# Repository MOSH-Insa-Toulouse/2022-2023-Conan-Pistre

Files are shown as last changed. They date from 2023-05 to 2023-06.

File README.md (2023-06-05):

# 2022-2023-Conan-Pistre

fake-it-till-u-make-it (1)




Ce projet s'inscrit dans l'UF "*Du capteur au banc de Test*". Il consiste en l'élaboration d'un capteur de déformation/Jauge de contrainte à base de graphite.
**Design**, **Conception**, **Test** et **Codage** de notre Capteur et de son circuit sont détaillés ci-dessous.

## Descriptif du Projet

Notre projet se sépare en deux axes précis:
 - Le développement d'une partie *Professionnelle* permettant depuis une application et un affichage OLED d'obtenir les valeurs de résistance de notre capteur
 - Le développement d'une partie *Fun* permettant une application pratique du capteur pour jouer au Dino Game de google.

Social_dino-with-hat 

## Sommaire

* [Tests et Mesures LTSpice : circuit amplificateur Transimpédance à deux étages](#PremiereSection)
* [Fabrication du Shield](#DeuxiemeSection)
  * [Composants designés : Symboles & empreintes](#DeuxiemeSection1)
  * [Schématique](#DeuxiemeSection2)
  * [Placement des composants](#DeuxiemeSection3)
  * [Réalisation du PCB](#DeuxiemeSection4)
  * [Perçage et soudure](#DeuxiemeSection5)
* [Code Arduino](#TroisiemeSection)
  * [Lecture de la valeur de la Résistance](#TroisiemeSection1)
  * [Gestion du BlueTooth](#TroisiemeSection2)
  * [Gestion de l'affichage OLED](#TroisiemeSection3)
* [Application Smartphone APK](#QuatriemeSection)
* [Banc de test](#CinquiemeSection)
* [Datasheet](#SixiemeSection)

## Tests et Mesures LTSpice : circuit amplificateur Transimpédance à deux étages 

Les tests suivants ont été réalisés sur LTSpice 17.00.27.00 Le Schéma du circuit `ci-dessous` représente le circuit choisi pour optimiser les capacités de notre capteur. En effet ce dernier possédant une résistance élevée, il ne délivrera qu'un courant faible qu'il nous faut amplifier pour obtenir des résultats exploitables par notre programme Arduino réalisé sur Arduino 1.8.19.

**Schéma électrique Optimisé**
238069557-073e9e18-b402-41fa-b7d9-c79b0854c814

Ce circuit possède 3 filtres ayant chacun leur utilité :
 - `en rouge` le filtre passe bas passif permet donc filtrer les perturbations et les excès de bruit en courant sur la forme du signal d'entrée, il possède une fréquence de coupure aux alentour de 16Hz.
 - `en vert` le filtre passe haut actif permet de supprimer la composante parasite de 50Hz qui vient perturber le signal, il possède une fréqence de 1,6Hz.
 - `en violet` le filtre passe bas passif permet limiter le bruit lors du traitement du signal, il possède une fréquence de 1,6kHz.

Passons maintenant à la simulation de notre circuit afin d'en évaluer l'optimisation :

**Vérification du la tension de sortie du montage avec un courant d'entrée égal à 100nA**
Test 100nA

Comme constaté `ci-dessus` notre circuit permet bien un gain de 100dB ce qui permet une nette augmentation du signal de sortie par rapport au signal d'entrée.

## Fabrication du Shield 

Pour fabriquer notre PCB nous avons du le designer sur KICAD 7.0. Nous avons ajouté au circuit précédent un écran OLED, un encodeur rotatoire ainsi qu'un module Bluetooth afin d'exploiter les résultats de notre capteur.

### Composants designés : Symboles & empreintes 

* Ecran OLED 

 

* Module Bluetooth

 
 

* Amplificateur LT1050 


 

* Capteur Graphite 

 
 

* Encodeur Rotatoire

 
 

### Schématique 

Une fois les symboles et empreintes créés, nous avons réalisé le schéma de notre shield. En haut à gauche sont représentées les broches de la carte Arduino. Au milieu est représenté le cicuit comprenant notre capteur et l'amplificateur transimpédance et juste au-dessus se trouvent l'écran OLED, le module bluetooth et l'encodeur rotatoire.

schématique

### Placement des composants 

schématique

### Réalisation du PCB 

Le PCB a été réalisé avec l'aide de Cathy. Notre PCB a été fabriqué à partir d'une plaque d'Epoxy recouverte d'une fine couche de cuivre (≃ 60μm). Nous avons imprimé sur du papier calque la modélisation de notre PCB réalisée sur KICAD pour ensuite insoler notre plaquette aux UV avec le calque par-dessus pendant quelques minutes. À l'aide d'un révélateur, nous avons retiré la partie de la résine non insolée. La plaquette d'Epoxy est ensuite placée dans un bain de perchlorure de fer pour la gravure, cette opération dure en moyenne 7-9min. Le cuivre non protégé par la résine est ainsi retiré de la plaquette ce qui nous permet d'obtenir notre PCB correspondant à notre KICAD. Enfin, un rincage à l'acétone est réalisé sur la plaquette pour éliminer les dernières traces de résine.

### Perçage et soudure 

Nous avons ensuite percé notre PCB aux emplacements où les différents composants seront insérés à l'aide d'une perceuse électrique. Le diamètre des trous dépend des différents composants à placer :

⌀ 0.8mm : AOP LTC1050, résistances et capacités
⌀ 1.0mm : Broches de connexion de la carte Arduino Uno et headers des différents modules (OLED, bluetooth, encodeur rotatoire)

## Code Arduino 
### Lecture de la valeur de la Résistance 
### Gestion du BlueTooth 
### Gestion de l'affichage OLED 
## Application Smartphone APK 
## Banc de test 

Pour réaliser notre phase de test, nous avons utilisé le banc de test réalisé lors des années précédentes : 7 demi-cercles en plastique, dont les diamètres varient de 2cm à 5cm. Le test alors réalisé est plutôt simple : nous mesurons différentes valeurs de résistance en courbant notre capteur sur le banc de test. Nous utilisons 3 capteurs préparés à l'aide de 3 types de crayons différents à dureté variable : un HB, un 1B et un 4B.

116738001-2dc50b00-a9f2-11eb-9315-dd29a9fe3ac9

Graph_tension

Graph_Compression

Les résultats obtenus semblent cohérents. En effet, une mine 4B dépose plus de graphite qu'une mine 1B elle même plus généreuse qu'une mine HB. Le dépôt de graphite plus important entraine une résistance globale plus faible. Nos capteurs ont bien une résistance variable selon leur déformation comme attendus d'une jauge de contrainte. Petit bémol cependant à constater : l'espérance de vie du capteur est très faible, après la série de tests il n'est déjà quasi plus utilisable. Cela réduit bien evidemment ses chances d'utilisation à grande échelle.

## Datasheet

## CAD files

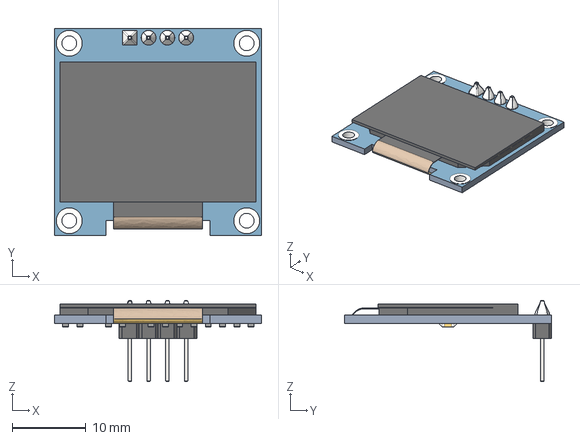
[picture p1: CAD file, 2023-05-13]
Kicad/Kicad/Banc de test/OLED/0.96 OLED v3.step
28.0 x 28.0 x 11.0 mm

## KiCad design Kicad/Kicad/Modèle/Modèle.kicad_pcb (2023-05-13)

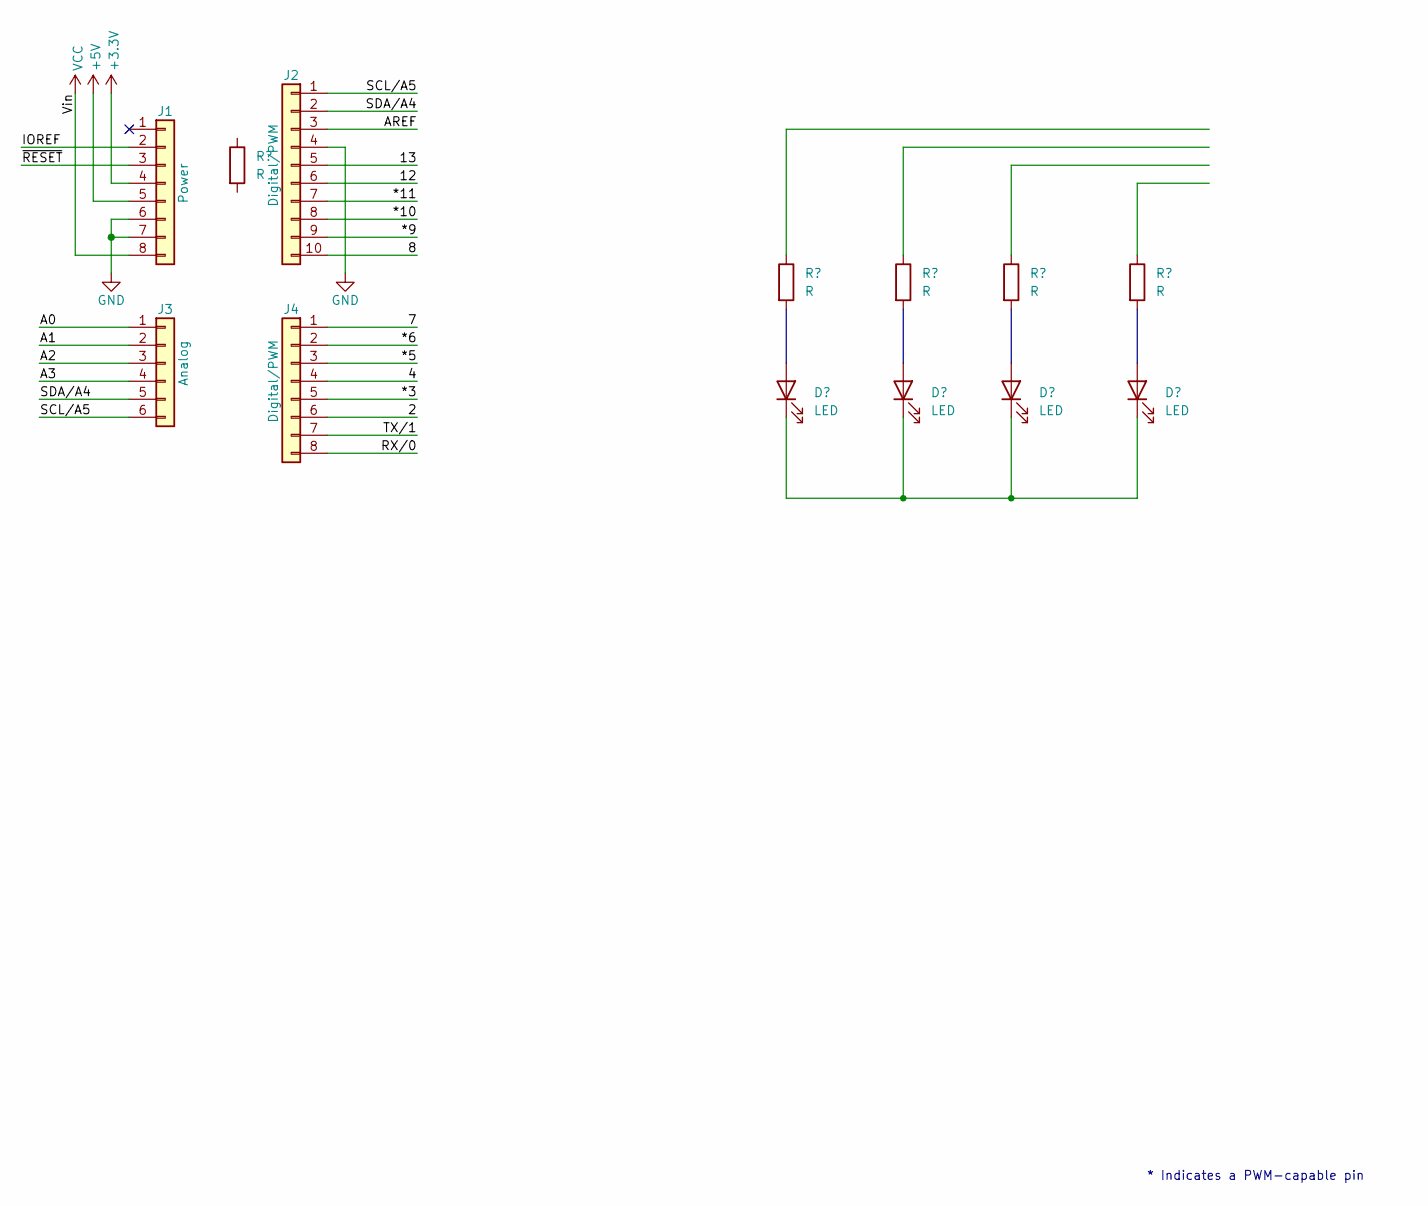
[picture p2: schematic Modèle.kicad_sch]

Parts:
J1: Power; PinSocket_1x08_P2.54mm_Vertical
J2: Digital/PWM; PinSocket_1x10_P2.54mm_Vertical
J3: Analog; PinSocket_1x06_P2.54mm_Vertical
J4: Digital/PWM; PinSocket_1x08_P2.54mm_Vertical

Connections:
+3V3: J1.4
+5V: J1.5
/2: J4.6
/4: J4.4
/7: J4.1
/8: J2.10
/12: J2.6
/13: J2.5
/*3: J4.5
/*5: J4.3
/*6: J4.2
/*9: J2.9
/*10: J2.8
/*11: J2.7
/A0: J3.1
/A1: J3.2
/A2: J3.3
/A3: J3.4
/AREF: J2.3
/IOREF: J1.2
/RX/0: J4.8
/SCL/A5: J2.1, J3.6
/SDA/A4: J2.2, J3.5
/TX/1: J4.7
/~RESET: J1.3
GND: J1.6, J1.7, J2.4
VCC: J1.8

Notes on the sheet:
* Indicates a PWM-capable pin

Board: 2 copper layers, 8 parts (0 on the bottom side), 3 nets, no tracks yet.

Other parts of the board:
MH1, MH2, MH3, MH4: MountingHole_3.2mm

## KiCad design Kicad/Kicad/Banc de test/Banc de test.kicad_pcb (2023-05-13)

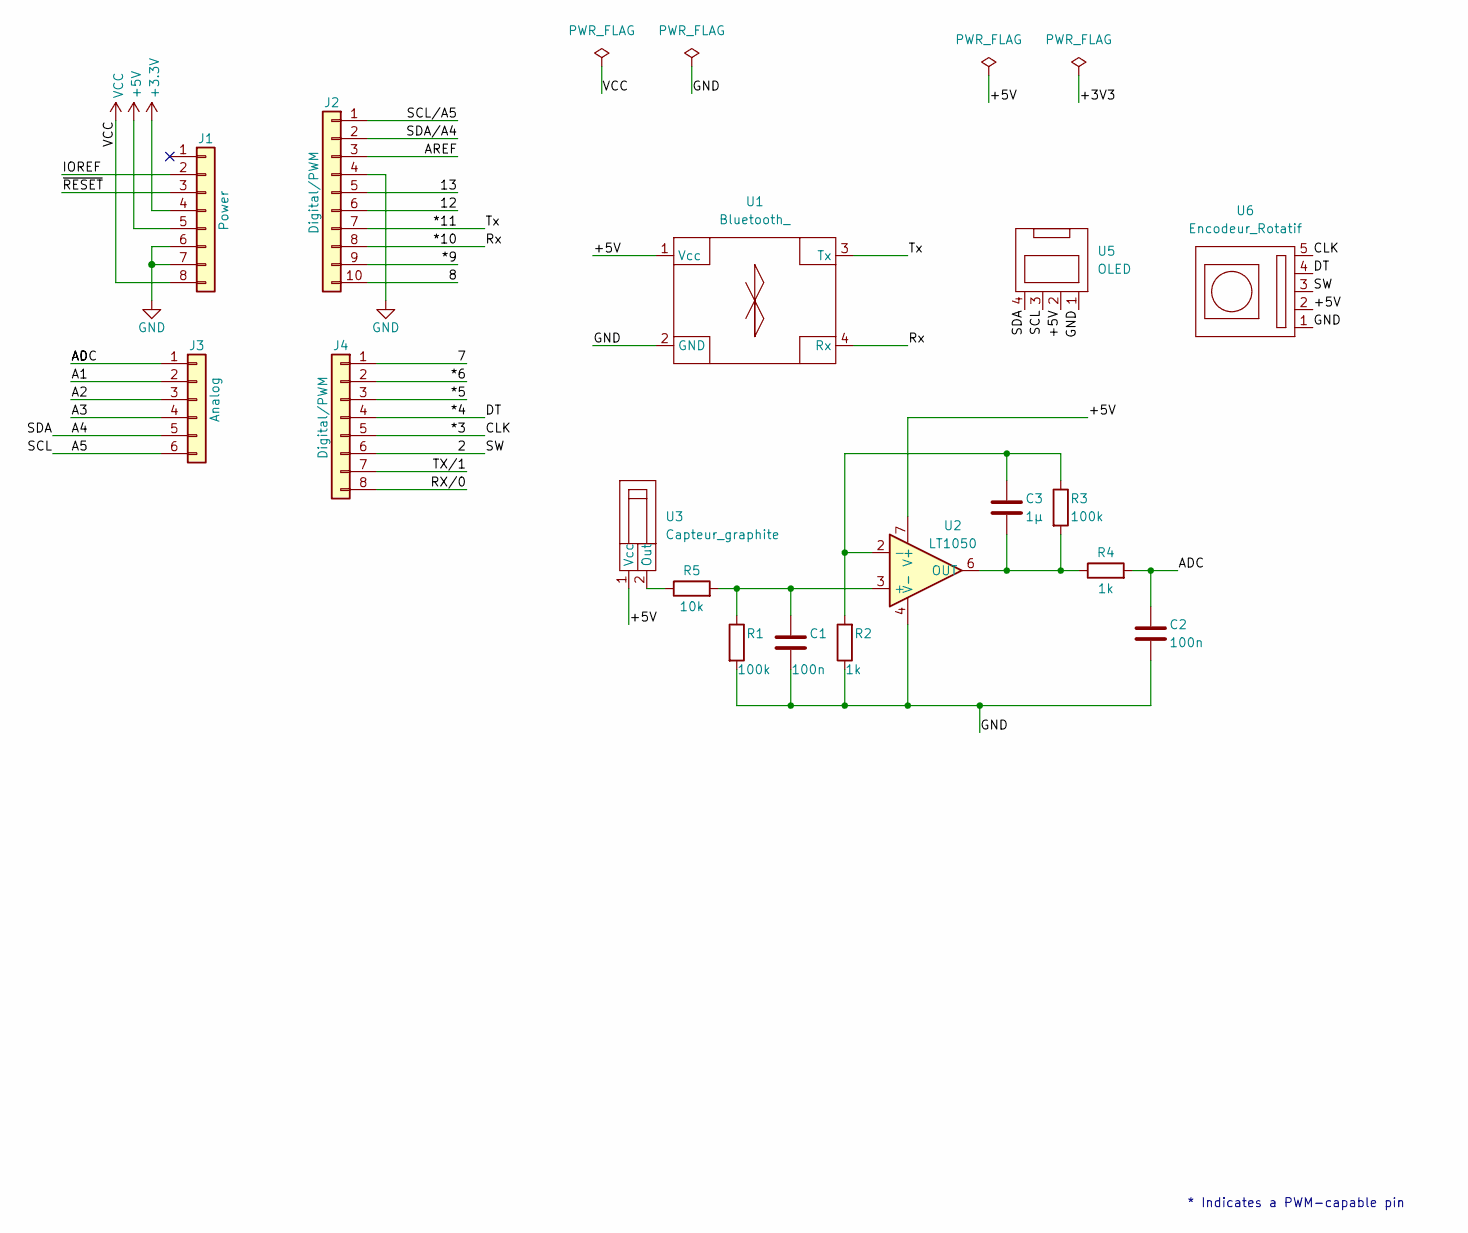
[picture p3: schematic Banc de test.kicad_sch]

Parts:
C1, C2: 100n; C_Disc_D5.0mm_W2.5mm_P5.00mm
C3: 1µ; C1uK63
J1: Power; PinSocket_1x08_P2.54mm_Vertical
J2: Digital/PWM; PinSocket_1x10_P2.54mm_Vertical
J3: Analog; PinSocket_1x06_P2.54mm_Vertical
J4: Digital/PWM; PinSocket_1x08_P2.54mm_Vertical
R1, R3: 100k; R_Axial_DIN0207_L6.3mm_D2.5mm_P10.16mm_Horizontal
R2, R4: 1k; R_Axial_DIN0207_L6.3mm_D2.5mm_P10.16mm_Horizontal
R5: 10k; R_Axial_DIN0207_L6.3mm_D2.5mm_P10.16mm_Horizontal
U1: Bluetooth_; Bluetooth_Empreinte
U2: LT1050; LTC1050
U3: Capteur_graphite; Graphite
U5: OLED
U6: Encodeur_Rotatif; Encodeur

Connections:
+3V3: J1.4
+5V: J1.5, U1.1 (Vcc), U2.7 (V+), U3.1 (Vcc), U5.2, U6.2
/2: J4.6, U6.3
/7: J4.1
/8: J2.10
/12: J2.6
/13: J2.5
/*3: J4.5, U6.5
/*4: J4.4, U6.4
/*5: J4.3
/*6: J4.2
/*9: J2.9
/*10: J2.8, U1.4 (Rx)
/*11: J2.7, U1.3 (Tx)
/A0: C2.2, J3.1, R4.2
/A1: J3.2
/A2: J3.3
/A3: J3.4
/A4: J3.5, U5.4
/A5: J3.6, U5.3
/AREF: J2.3
/IOREF: J1.2
/RX/0: J4.8
/SCL/A5: J2.1
/SDA/A4: J2.2
/TX/1: J4.7
/~RESET: J1.3
GND: C1.1, C2.1, J1.6, J1.7, J2.4, R1.2, R2.1, U1.2 (GND), U2.4 (V-), U5.1, U6.1
unnamed: C1.2, R1.1, R5.2, U2.3 (+)
unnamed: C3.1, R3.2, R4.1, U2.6 (OUT)
unnamed: C3.2, R2.2, R3.1, U2.2 (-)
unnamed: R5.1, U3.2 (Out)
VCC: J1.8

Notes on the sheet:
* Indicates a PWM-capable pin

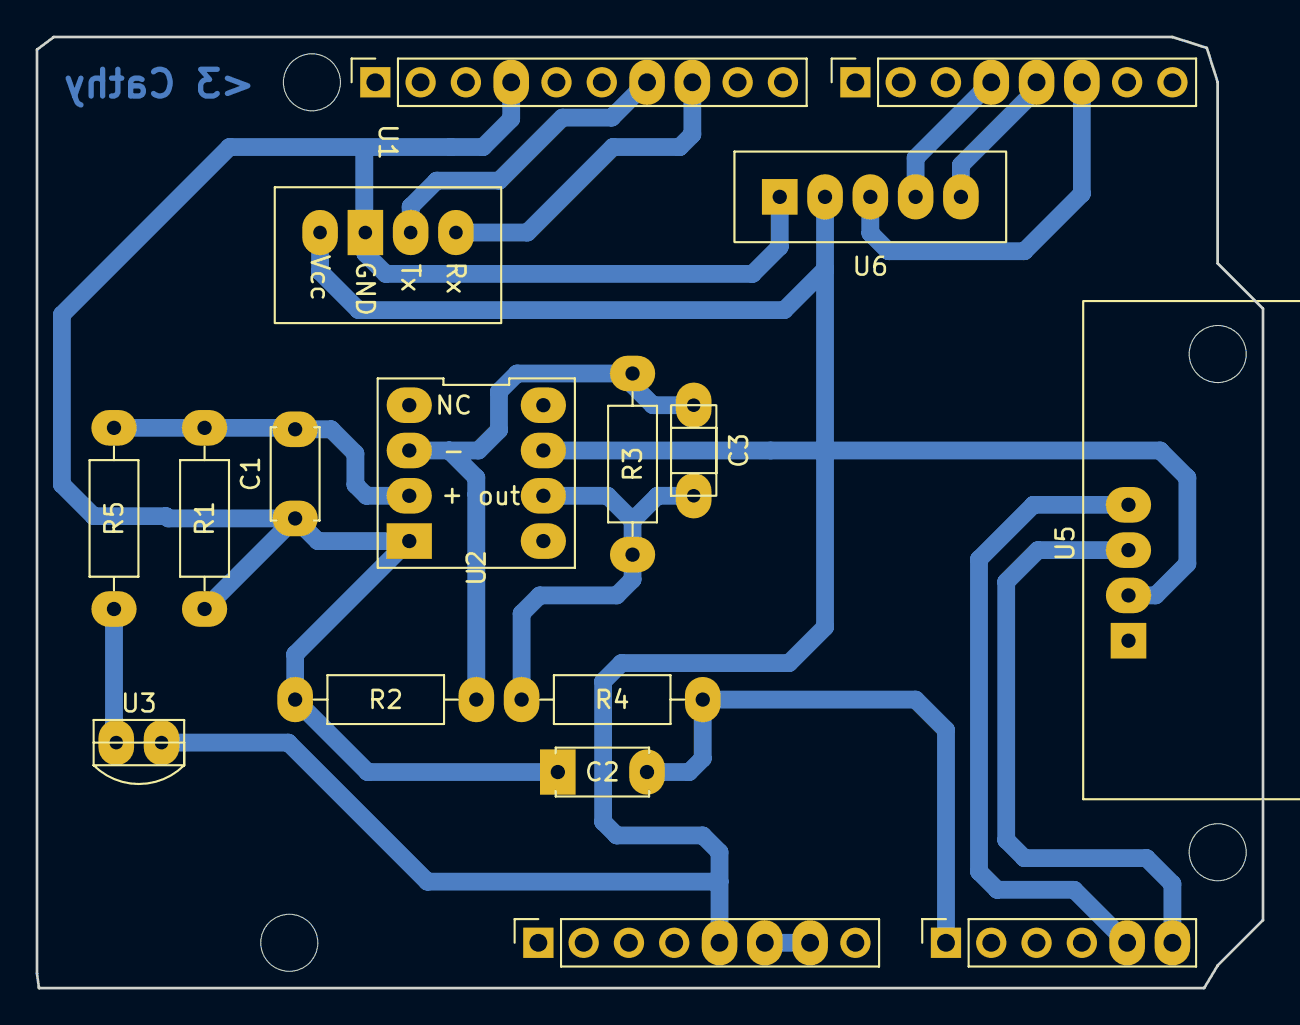
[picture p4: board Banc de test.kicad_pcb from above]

Board: 2 copper layers, 68.8 x 53.3 mm, 21 parts (0 on the bottom side), 14 nets.

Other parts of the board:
MH1, MH2, MH3, MH4: MountingHole_3.2mm

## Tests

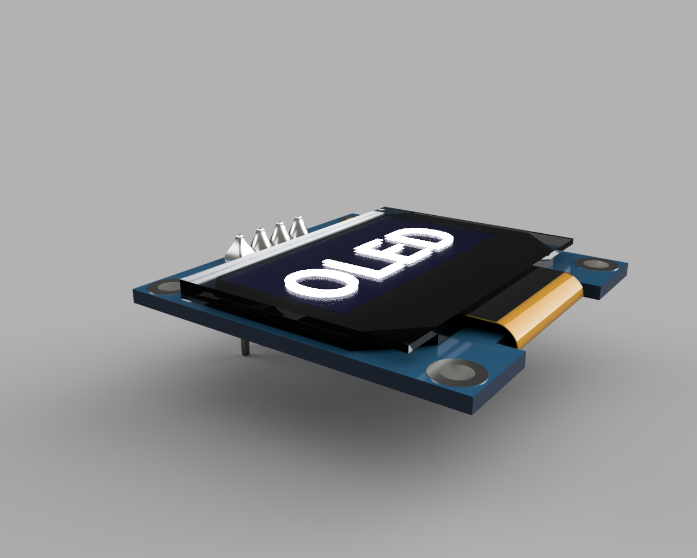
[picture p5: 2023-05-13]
Kicad/Kicad/Banc de test/OLED/37782fbc-3a18-452d-9e60-ae984feaae57.PNG

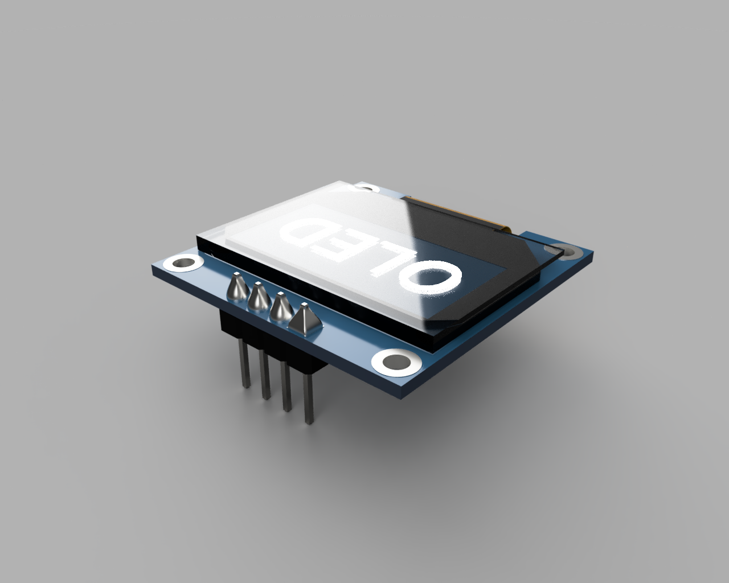
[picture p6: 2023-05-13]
Kicad/Kicad/Banc de test/OLED/0.96_OLED_Dugme_2019-Oct-16_09-50-47AM-000_CustomizedView2336291954.png

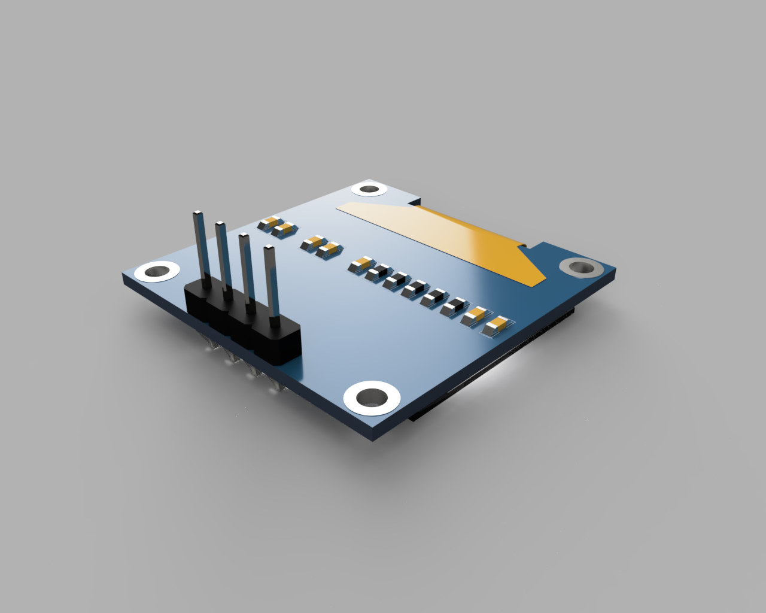
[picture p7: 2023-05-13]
Kicad/Kicad/Banc de test/OLED/0.96_OLED_Dugme_2019-Oct-16_09-51-55AM-000_CustomizedView47831114539.png

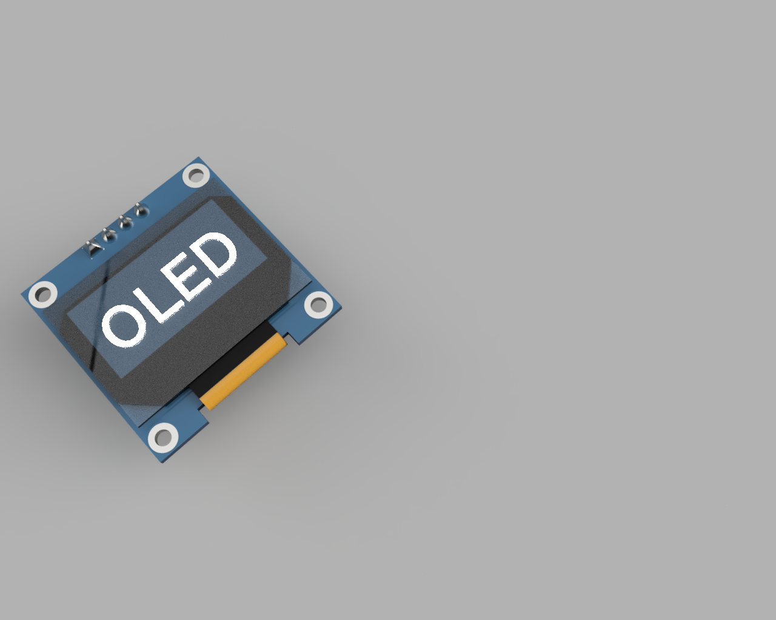
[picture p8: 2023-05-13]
Kicad/Kicad/Banc de test/OLED/0.96_OLED_Dugme_2019-Oct-16_09-53-48AM-000_CustomizedView8478028364.png

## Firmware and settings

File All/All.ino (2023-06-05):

////////////////////////////////// INCLUDE //////////////////////////////////
#include <Wire.h>
#include <Adafruit_GFX.h>
#include <Adafruit_SSD1306.h>
#include <SoftwareSerial.h>

////////////////////////////////// DEFINE ///////////////////////////////////

#define rxPin 11 //Broche 11 en tant que RX, � raccorder sur TX du HC-05
#define txPin 10 //Broche 10 en tant que TX, � raccorder sur RX du HC-05
SoftwareSerial HC05(rxPin ,txPin); //D�finition du software serial

#define SCREEN_WIDTH 128 // OLED display width, in pixels
#define SCREEN_HEIGHT 64 // OLED display height, in pixels
#define OLED_RESET 4     // Reset pin # (or -1 if sharing Arduino reset pin)
#define SCREEN_ADDRESS 0x3C

//Parameters Sensor
#define Vcc 5.0
#define R1 100000.0
#define R2 1000.0
#define R3 100000.0
#define R5 10000.0

//Parameters for game
#define DINO_WIDTH 25
#define DINO_HEIGHT 26
#define DINO_INIT_X 10 // Dino initial spawn location
#define DINO_INIT_Y 10 // Dino initial spawn location

#define BASE_LINE_X 0
#define BASE_LINE_Y 10
#define BASE_LINE_X1 127
#define BASE_LINE_Y1 10

#define TREE1_WIDTH 11
#define TREE1_HEIGHT 23

#define TREE2_WIDTH 22
#define TREE2_HEIGHT 23

#define TREE_Y 10

#define JUMP_PIXEL 22 // Number of pixel dino will jump

Adafruit_SSD1306 display(OLED_RESET);
//Adafruit_SSD1306 display(SCREEN_WIDTH, SCREEN_HEIGHT, &Wire, OLED_RESET);




///////////////////////////////// VARIABLES /////////////////////////////////
// Encoder
int encoderDT = 4;  
int encoderCLK = 3;
int encoderSW = 2;
volatile int lastEncoded = 0;
volatile long encoderValue = 0;
// Menu
bool screenOn = false;
int click = 0 ; 
int lastMSB = 0;
int lastLSB = 0;
int selected= 0;
int numMenu = 3;      
String menuItems[] = {"1- Easy Mode", "2- Gettin Tough", "3- Good Luck lol"};
String initial[] = {"PLAY","TEST", "OFF"} ;
String endgame[] = {"PLAY AGAIN","MAIN MENU", "OFF"} ;

/***************************************/
// Jump
float resistance ; 
float min = 100000.0 ; 
float max = -100000.0 ; 
float range ; 
float middle ; 
int i=0 ; 

/***************************************/
//Parameters for game
bool collision = false ; 

static const unsigned char PROGMEM dino1[]={
  // 'dino', 25x26px
0x00, 0x00, 0x00, 0x00, 0x00, 0x07, 0xfe, 0x00, 0x00, 0x06, 0xff, 0x00, 0x00, 0x0e, 0xff, 0x00, 
0x00, 0x0f, 0xff, 0x00, 0x00, 0x0f, 0xff, 0x00, 0x00, 0x0f, 0xff, 0x00, 0x00, 0x0f, 0xc0, 0x00, 
0x00, 0x0f, 0xfc, 0x00, 0x40, 0x0f, 0xc0, 0x00, 0x40, 0x1f, 0x80, 0x00, 0x40, 0x7f, 0x80, 0x00, 
0x60, 0xff, 0xe0, 0x00, 0x71, 0xff, 0xa0, 0x00, 0x7f, 0xff, 0x80, 0x00, 0x7f, 0xff, 0x80, 0x00, 
0x7f, 0xff, 0x80, 0x00, 0x3f, 0xff, 0x00, 0x00, 0x1f, 0xff, 0x00, 0x00, 0x0f, 0xfe, 0x00, 0x00, 
0x03, 0xfc, 0x00, 0x00, 0x01, 0xdc, 0x00, 0x00, 0x01, 0x8c, 0x00, 0x00, 0x01, 0x8c, 0x00, 0x00, 
0x01, 0x0c, 0x00, 0x00, 0x01, 0x8e, 0x00, 0x00
};

static const unsigned char PROGMEM tree1[]={
  // 'tree1', 11x23px
0x1e, 0x00, 0x1f, 0x00, 0x1f, 0x40, 0x1f, 0xe0, 0x1f, 0xe0, 0xdf, 0xe0, 0xff, 0xe0, 0xff, 0xe0, 
0xff, 0xe0, 0xff, 0xe0, 0xff, 0xe0, 0xff, 0xe0, 0xff, 0xc0, 0xff, 0x00, 0xff, 0x00, 0x7f, 0x00, 
0x1f, 0x00, 0x1f, 0x00, 0x1f, 0x00, 0x1f, 0x00, 0x1f, 0x00, 0x1f, 0x00, 0x1f, 0x00
};

static const unsigned char PROGMEM tree2[]={
  // 'tree2', 22x23px
0x1e, 0x01, 0xe0, 0x1f, 0x03, 0xe0, 0x1f, 0x4f, 0xe8, 0x1f, 0xff, 0xfc, 0x1f, 0xff, 0xfc, 0xdf, 
0xff, 0xfc, 0xff, 0xff, 0xfc, 0xff, 0xff, 0xfc, 0xff, 0xff, 0xfc, 0xff, 0xff, 0xfc, 0xff, 0xff, 
0xfc, 0xff, 0xef, 0xfc, 0xff, 0x83, 0xfc, 0xff, 0x03, 0xfc, 0xff, 0x03, 0xf8, 0x7f, 0x03, 0xe0, 
0x1f, 0x03, 0xe0, 0x1f, 0x03, 0xe0, 0x1f, 0x03, 0xe0, 0x1f, 0x03, 0xe0, 0x1f, 0x03, 0xe0, 0x1f, 
0x03, 0xe0, 0x1f, 0x03, 0xe0
};




////////////////////////////// CONFIGURATION ////////////////////////////////
void setup() {
  Serial.begin(9600) ; 
  pinMode(rxPin,INPUT);
  pinMode(txPin,OUTPUT);
  HC05.begin(9600);
 
  // SSD1306_SWITCHCAPVCC = generate display voltage from 3.3V internally
  if(!display.begin(SSD1306_SWITCHCAPVCC, SCREEN_ADDRESS)) {
    Serial.println(F("SSD1306 allocation failed"));
    for(;;); // Don't proceed, loop forever
  }

  display.clearDisplay();  //Clear the buffer
  display.display();
  /***************************************/
  pinMode(encoderDT, INPUT_PULLUP);
  pinMode(encoderCLK, INPUT_PULLUP); 
  pinMode(encoderSW, INPUT_PULLUP); 

  attachInterrupt(digitalPinToInterrupt(encoderDT), updateEncoder, CHANGE);
  attachInterrupt(digitalPinToInterrupt(encoderCLK), updateEncoder, CHANGE);
  /***************************************/
  Wire.begin();
  //display.clearDisplay();
}


////////////////////////////////// FUNCTIONS ////////////////////////////////

///////////////// INTRO MESSAGE /////////////////
void introMessage(){
  display.setTextSize(2);             // Draw 2X-scale text
  display.setTextColor(SSD1306_WHITE);
  display.setCursor(10,4);
  display.println("Dino Game");
  display.display();
}

/////////////////// MOVE DINO ///////////////////
void moveDino(int16_t *y, int type=0){
  display.drawBitmap(DINO_INIT_X, *y, dino1, DINO_WIDTH, DINO_HEIGHT, SSD1306_WHITE);
}

/////////////////// MOVE TREE /////////////////// 
void moveTree(int16_t *x, int type=0){
  if(type==0){
    display.drawBitmap(*x, TREE_Y, tree1, TREE1_WIDTH, TREE1_HEIGHT, SSD1306_WHITE);
  }
  else if(type==1){
    display.drawBitmap(*x, TREE_Y, tree2, TREE2_WIDTH, TREE2_HEIGHT, SSD1306_WHITE);
  }
  
}

///////// GAME OVER DISPLAY WITH SCORE //////////
void gameOver(){
  display.clearDisplay();
  
  display.setTextSize(2);             
  display.setTextColor(SSD1306_WHITE);
  display.setCursor(15,0);
  display.println("Game Over");
  
  display.setTextSize(1);
  display.setCursor(10,20);
  display.println(endgame[selected]) ;

  display.display();
}

////////////// MAIN PLAY FUNCTION ///////////////
bool play(){
  bool collision = false ;  
  int16_t tree_x=127;
  int16_t tree1_x=195;
  int tree_type = random(0,2);
  int tree_type1 = random(0,2);
  int16_t dino_y = DINO_INIT_Y;
  int input_command;
  int jump=0;
  int score=0;
    
  for(;;){
    display.clearDisplay();   
      
    if(GetSensor()*4 >= middle){
      if(jump==0){
        jump=1;
      }
    }

    if(jump==1){
      dino_y--;
      if(dino_y== (DINO_INIT_Y-JUMP_PIXEL)){
        jump=2;
        score++;
      }
    } else if(jump==2){
      dino_y++;
      if(dino_y== DINO_INIT_Y){
        jump=0; 
      }
    }

    if(tree_x<= (DINO_INIT_X+DINO_WIDTH) && tree_x>= (DINO_INIT_X+(DINO_WIDTH/2))){
    // Serial.println("Might be Collision Happend");
      if(dino_y>=(DINO_INIT_Y-3)){
        // Collision Happened
        Serial.println("Collision Happend");
        collision = true ; 
        break;
      }    
    }

    if(tree1_x<= (DINO_INIT_X+DINO_WIDTH) && tree1_x>= (DINO_INIT_X+(DINO_WIDTH/2))){
    // Serial.println("Might be Collision Happend");
      if(dino_y>=(DINO_INIT_Y-3)){
        // Collision Happened
        Serial.println("Collision Happend");
        collision = true ; 
        break;
      }    
    }

    displayScore(score);
    moveTree(&tree_x,tree_type);
    moveTree(&tree1_x,tree_type1);
    moveDino(&dino_y);
    display.drawLine(0, 54, 127, 54, SSD1306_WHITE);

    tree_x--;
    tree1_x--;
    if(tree_x==0) {
      tree_x = 127;
      tree_type = random(0,1);
    }

    if(tree1_x==0) {
      tree1_x = 195;
      tree_type1 = random(0,1);
    }
   display.display();
  }
  Serial.println("Game Over");
  return collision ; 
}

//////// DISPLAY SCORE WHILE GAME RUNNING ///////
void displayScore(int score){
  display.setTextSize(1);
  display.setCursor(64,2);
  display.print("Score: ");
  display.print(score);
}

///////////////// RENDER SCENE //////////////////
void renderScene(int16_t i=0){
  display.drawBitmap(10, 29, dino1, 25, 26, SSD1306_WHITE);
  display.drawBitmap(50, TREE_Y, tree1, 11, 23, SSD1306_WHITE);
  display.drawBitmap(100, TREE_Y, tree2, 22, 23, SSD1306_WHITE);
  display.drawLine(0, 54, 127, 54, SSD1306_WHITE);
  display.drawPixel(i, 60, SSD1306_WHITE);
}

/////////////// GET SENSOR VALUES ///////////////
int8_t GetSensor() {
  int sensorValue = analogRead(A0);
  float voltage = (float)sensorValue * (5.0 / 1023.0); // Convert the analog reading (0 - 1023) to a volt (0 - 5V):
  int8_t resistance = (0.000001*((R1*(R2+R3)/R2)*(Vcc/voltage)-R5-R1))/4; //Voltage to MOhm
  //Serial.println(resistance);  // print out the value you read
  //delay(100); 
  return resistance ; 
}


////////////////////////////////// PLAY /////////////////////////////////////
void loop() { 
  //Click conditions****************************************/
  if (digitalRead(encoderSW)==LOW && click==0)  {
    click = 1 ; 
  } else if (digitalRead(encoderSW)==LOW && click ==1 && initial[selected]=="PLAY"){
    click = 2 ; 
  } else if (digitalRead(encoderSW)==LOW && click ==1 && initial[selected]=="TEST"){
    click = 4 ; 
  } else if (digitalRead(encoderSW)==LOW && click ==1 && initial[selected]=="OFF"){
    click = 0 ; 
  } else if (digitalRead(encoderSW)==LOW && click ==4){
    click = 1 ; 
  } else if (digitalRead(encoderSW)==LOW && click ==2){
    click = 3 ; 
  } else if (i>=100 && click==3){
    click = 5 ; 
  } else if (digitalRead(encoderSW)==LOW && click ==7 && endgame[selected]=="OFF"){
    click = 0 ; 
  } else if (digitalRead(encoderSW)==LOW && click ==7 && endgame[selected]=="PLAY AGAIN"){
    collision = false ;
    click = 3 ; 
  } else if (digitalRead(encoderSW)==LOW && click ==7 && endgame[selected]=="MAIN MENU"){
    click = 1 ; 
  } 

  Serial.println(click) ; 

  /////// SCREEN OFF ////////
  if (click==0){
    display.clearDisplay();
    display.display();
  /*********************************************************/

  //////// MAIN MENU ////////
  } else if (click==1) {
    display.clearDisplay();
    display.setTextSize(1);
    display.setTextColor(SSD1306_WHITE);
    display.setCursor(50,0);
    display.println("Hi :)");
    display.setCursor(20,10);
    display.println("select a mode");
    display.setCursor(50, 20);
    display.println(initial[selected]) ;
    display.display();
  /*********************************************************/

  //////// DIFFICULTY ///////
  } else if (click ==2) {
    display.clearDisplay();
    display.setTextSize(1);
    display.setTextColor(SSD1306_WHITE);
    display.setCursor(30,0);
    display.println("Difficulty");
    display.setCursor(0, 12);
    display.println(menuItems[selected]);
    display.display();
  /*********************************************************/

  /////// SENSOR VAL ////////
  } else if (click == 4) {
    display.clearDisplay();
    display.setTextSize(1);
    display.setTextColor(SSD1306_WHITE);
    display.setCursor(20,0);
    display.println("Sensor values");
    display.setCursor(50,13) ; 
    display.println(GetSensor()*4) ;
    HC05.write(GetSensor());
    display.setCursor(20,25);
    display.println("click to EXIT");
    display.display();
  /*********************************************************/

  /////// CALIBRATION ///////
  } else if (click == 3) {
    display.clearDisplay();
    display.setTextSize(1);
    display.setTextColor(SSD1306_WHITE);
    display.setCursor(30,5);
    display.println("CALIBRATION");
    display.setCursor(10,15);
    display.println("please move sensor") ; 
    display.display();
    /*Calibration on 9000 values*****************/
    while (i<=1000){
     float resistance_nb = GetSensor()* 4 ; 
      Serial.println(resistance_nb) ; 
      if (resistance_nb>max){
        max = resistance_nb ;
      } else if (resistance_nb < min){
        min = resistance_nb ; 
      }
      i++ ;
    }

  } else if (click==5) {
    display.clearDisplay();
    display.setTextSize(1);
    display.setTextColor(SSD1306_WHITE);
    display.setCursor(17,5);
    display.println("CALIBRATION DONE");
    display.display();
    i=0 ;

    /*Intervals calculation**********************/
    range = max+min ; 
    middle = range/2; 
    delay(1500) ; 
    click = 6 ; 

  } else if (click ==6) {
    display.clearDisplay();
    display.setTextSize(1);
    display.setTextColor(SSD1306_WHITE);
    display.setCursor(0,5);
    display.print("No jump ");
    display.print(min) ; 
    display.print("-");
    display.print(middle) ; 
    display.setCursor(5,15);
    display.print("Jump ");
    display.print(middle) ; 
    display.print("-");
    display.print(max) ; 
    display.display();
    delay(2000) ; 
    display.clearDisplay();
    introMessage();
    delay(1000) ;

    click =  7;   
  /*********************************************************/

  ////////// GAME ///////////
  } else if (click==7) {
    if (collision==false){
      collision=play() ; 
    } else {
      gameOver();
    }
  }
}
  
void updateEncoder() {
  int MSB = digitalRead(encoderCLK);
  int LSB = digitalRead(encoderDT);

  int encoded = (MSB << 1) | LSB;
  int sum = (lastEncoded << 2) | encoded;

  if (sum == 0b1101 || sum == 0b0100 || sum == 0b0010 || sum == 0b1011) {
    encoderValue++;
  } else if (sum == 0b1110 || sum == 0b0111 || sum == 0b0001 || sum == 0b1000) {
    encoderValue--;
  }

  lastEncoded = encoded;

  if (encoderValue < 0) {
    encoderValue = 0;
  } else if (encoderValue >= numMenu) {
    encoderValue = numMenu - 1;
  }
  
  selected = encoderValue;
}
